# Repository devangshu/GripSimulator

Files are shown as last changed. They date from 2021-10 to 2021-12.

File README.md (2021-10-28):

# Grip Simulator

EE445L Final Project by Stefanie Thompson, Devangshu Goswami, Pulkit Mahajan, Anuv Gupta

## Notes

-   Password secret: `grip`
-   Serial format: `vpNum=vpValueNew\n` as `__=___...\n` ie. `03=245\n` or `12=1005\n`
    -   Two digits to represent the virtual pin number, then the full virtual pin integer value (any # of digits) followed by a newline character `\n`

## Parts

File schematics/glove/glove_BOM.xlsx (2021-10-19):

Part | Value | Device | Package | Description | POPULARITY | Column1
3.3V | TP_LOOP | TP_LOOP | TP_LOOP
5.0V | TP_LOOP | TP_LOOP | TP_LOOP
C1 | 4.7uf | CAPACITOR_POLARIZEDE5-6 | CAP200MILPOLARIZED | POLARIZED CAPACITOR, American symbol
C3 | 4.7uf | CAPACITOR_POLARIZEDE5-6 | CAP200MILPOLARIZED | POLARIZED CAPACITOR, American symbol
C5 | 4.7uf | CAPACITOR_POLARIZEDE5-6 | CAP200MILPOLARIZED | POLARIZED CAPACITOR, American symbol
C19 | 0.1uf | CAPACITOR050-024X044 | CAP200MIL | CAPACITOR, American symbol
GND | TP_LOOP | TP_LOOP | TP_LOOP
IC1 | LM2937 | LM2937 | TO220 | LM2937-2.5, LM2937-3.3 400mA and 500mA Voltage Regulators
JP1 |  | PINHD-1X2 | 1X02 | PIN HEADER
JP2 |  | PINHD-1X2 | 1X02 | PIN HEADER | 98
JP3 |  | PINHD-1X2 | 1X02 | PIN HEADER | 98
JP4 |  | PINHD-1X2 | 1X02 | PIN HEADER | 98
JP5 |  | PINHD-1X2 | 1X02 | PIN HEADER | 98
JP6 |  | PINHD-1X2 | 1X02 | PIN HEADER | 98
LED2 |  | LED3MM | LED3MM | Avago Technologies LED
R1 | 1K | RESISTOR0204/5 | RES200MIL | RESISTOR, American symbol
R3 | 10K | RESISTOR0204/7 | RES300MIL | RESISTOR, American symbol
U$1 | ESP_8266 | ESP_8266 | ESP8266
U$2 | TM4C_BP | TM4C_BP | TM4C_BOOSTER_PACK
U$5 | POWER_CONN | POWER_CONN | POWER_CONN
U$6 | SW_POWER_100MIL | SW_POWER_100MIL | SW_POWER

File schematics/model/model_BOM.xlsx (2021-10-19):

Column1 | Column2 | Column3 | Column4 | Column5 | Column6 | Column7
Part | Value | Device | Package | Description
3.3V | TP_LOOP | TP_LOOP | TP_LOOP
5.0V | TP_LOOP | TP_LOOP | TP_LOOP
C1 | 4.7uf | CAPACITOR_POLARIZEDE5-6 | CAP200MILPOLARIZED | POLARIZED CAPACITOR, American symbol
C3 | 4.7uf | CAPACITOR_POLARIZEDE5-6 | CAP200MILPOLARIZED | POLARIZED CAPACITOR, American symbol
C5 | 4.7uf | CAPACITOR_POLARIZEDE5-6 | CAP200MILPOLARIZED | POLARIZED CAPACITOR, American symbol
C19 | 0.1uf | CAPACITOR050-024X044 | CAP200MIL | CAPACITOR, American symbol
GND | TP_LOOP | TP_LOOP | TP_LOOP
IC1 | LM2937 | LM2937 | TO220 | LM2937-2.5, LM2937-3.3 400mA and 500mA Voltage Regulators
JP1 |  | PINHD-1X2 | 1X02 | PIN HEADER
JP2 |  | PINHD-1X3 | 1X03 | PIN HEADER
JP3 |  | PINHD-1X3 | 1X03 | PIN HEADER
JP4 |  | PINHD-1X3 | 1X03 | PIN HEADER
JP5 |  | PINHD-1X3 | 1X03 | PIN HEADER
JP6 |  | PINHD-1X3 | 1X03 | PIN HEADER
LED2 |  | LED3MM | LED3MM | Avago Technologies LED
R1 | 1K | RESISTOR0204/5 | RES200MIL | RESISTOR, American symbol
R3 | 10K | RESISTOR0204/7 | RES300MIL | RESISTOR, American symbol
U$1 | ESP_8266 | ESP_8266 | ESP8266
U$2 | TM4C_BP | TM4C_BP | TM4C_BOOSTER_PACK
U$5 | POWER_CONN | POWER_CONN | POWER_CONN
U$6 | SW_POWER_100MIL | SW_POWER_100MIL | SW_POWER

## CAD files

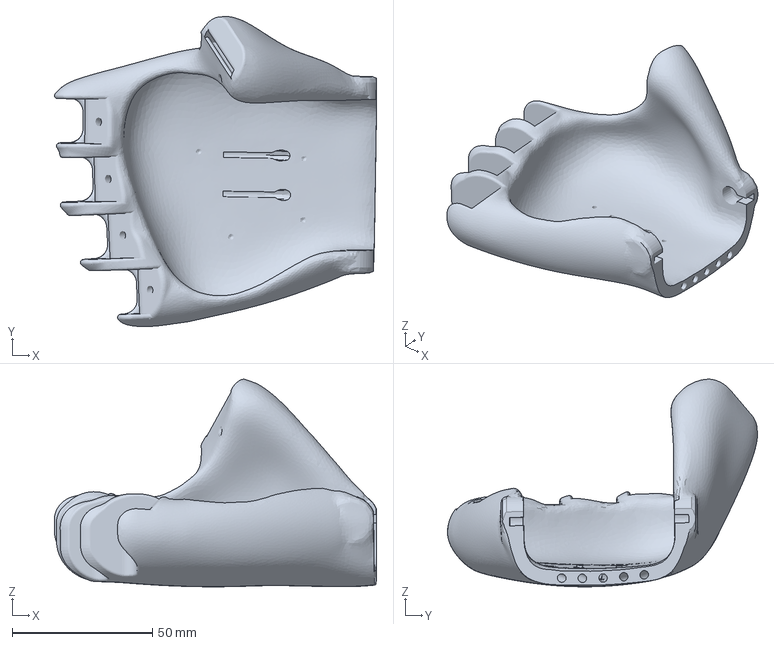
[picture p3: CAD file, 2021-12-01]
3d Models/RightHandPalmFullSizeBestQuality.3mf
115.0 x 110.7 x 74.1 mm

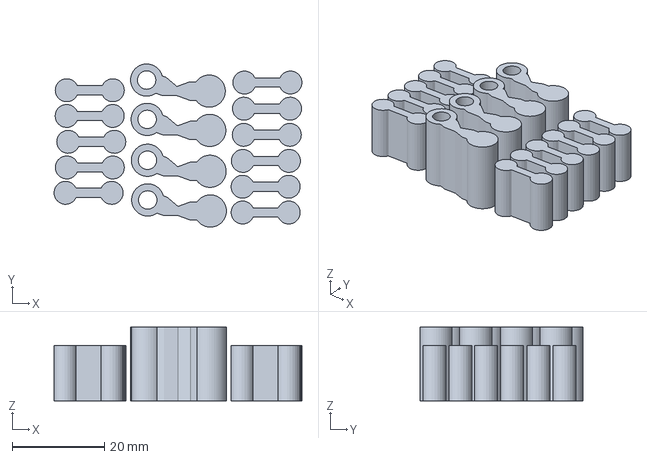
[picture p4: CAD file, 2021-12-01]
3d Models/FlexyPartProject.3mf
53.8 x 35.4 x 16.0 mm

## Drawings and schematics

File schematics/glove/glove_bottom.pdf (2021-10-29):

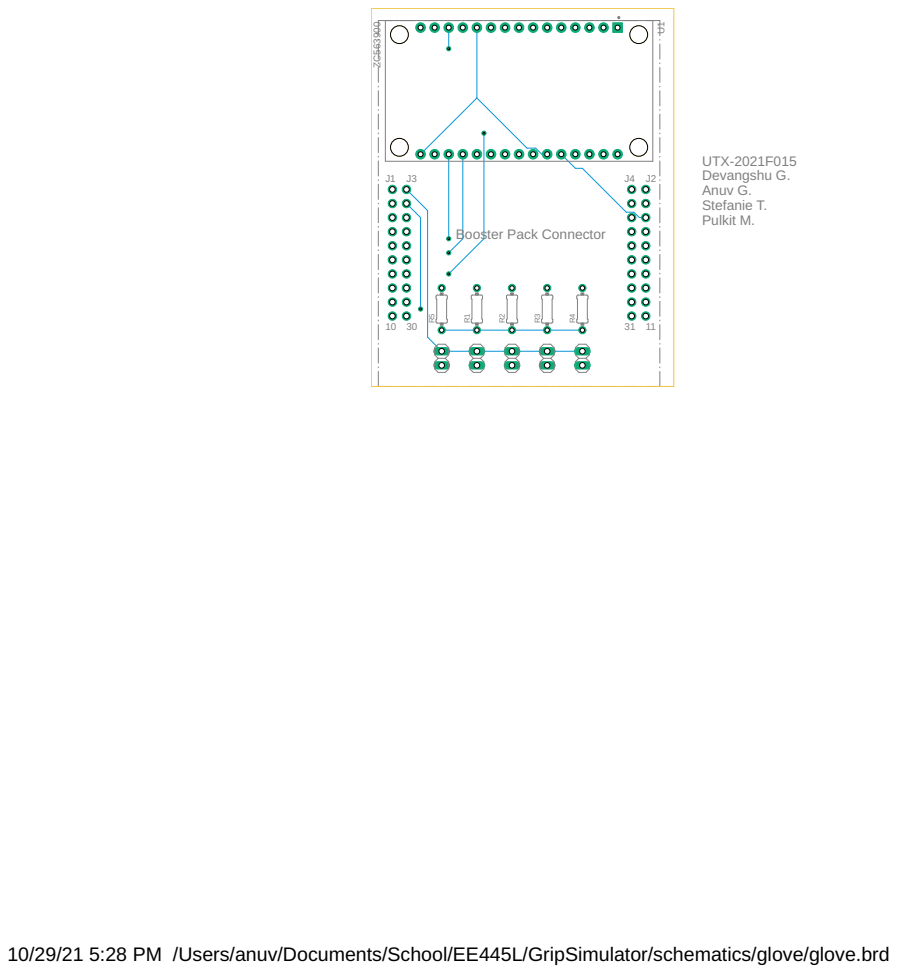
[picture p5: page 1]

Devangshu G. Anuv G. Stefanie T. Pulkit M.

10/29/21 5:28 PM /Users/anuv/Documents/School/EE445L/GripSimulator/schematics/glove/glove.brd

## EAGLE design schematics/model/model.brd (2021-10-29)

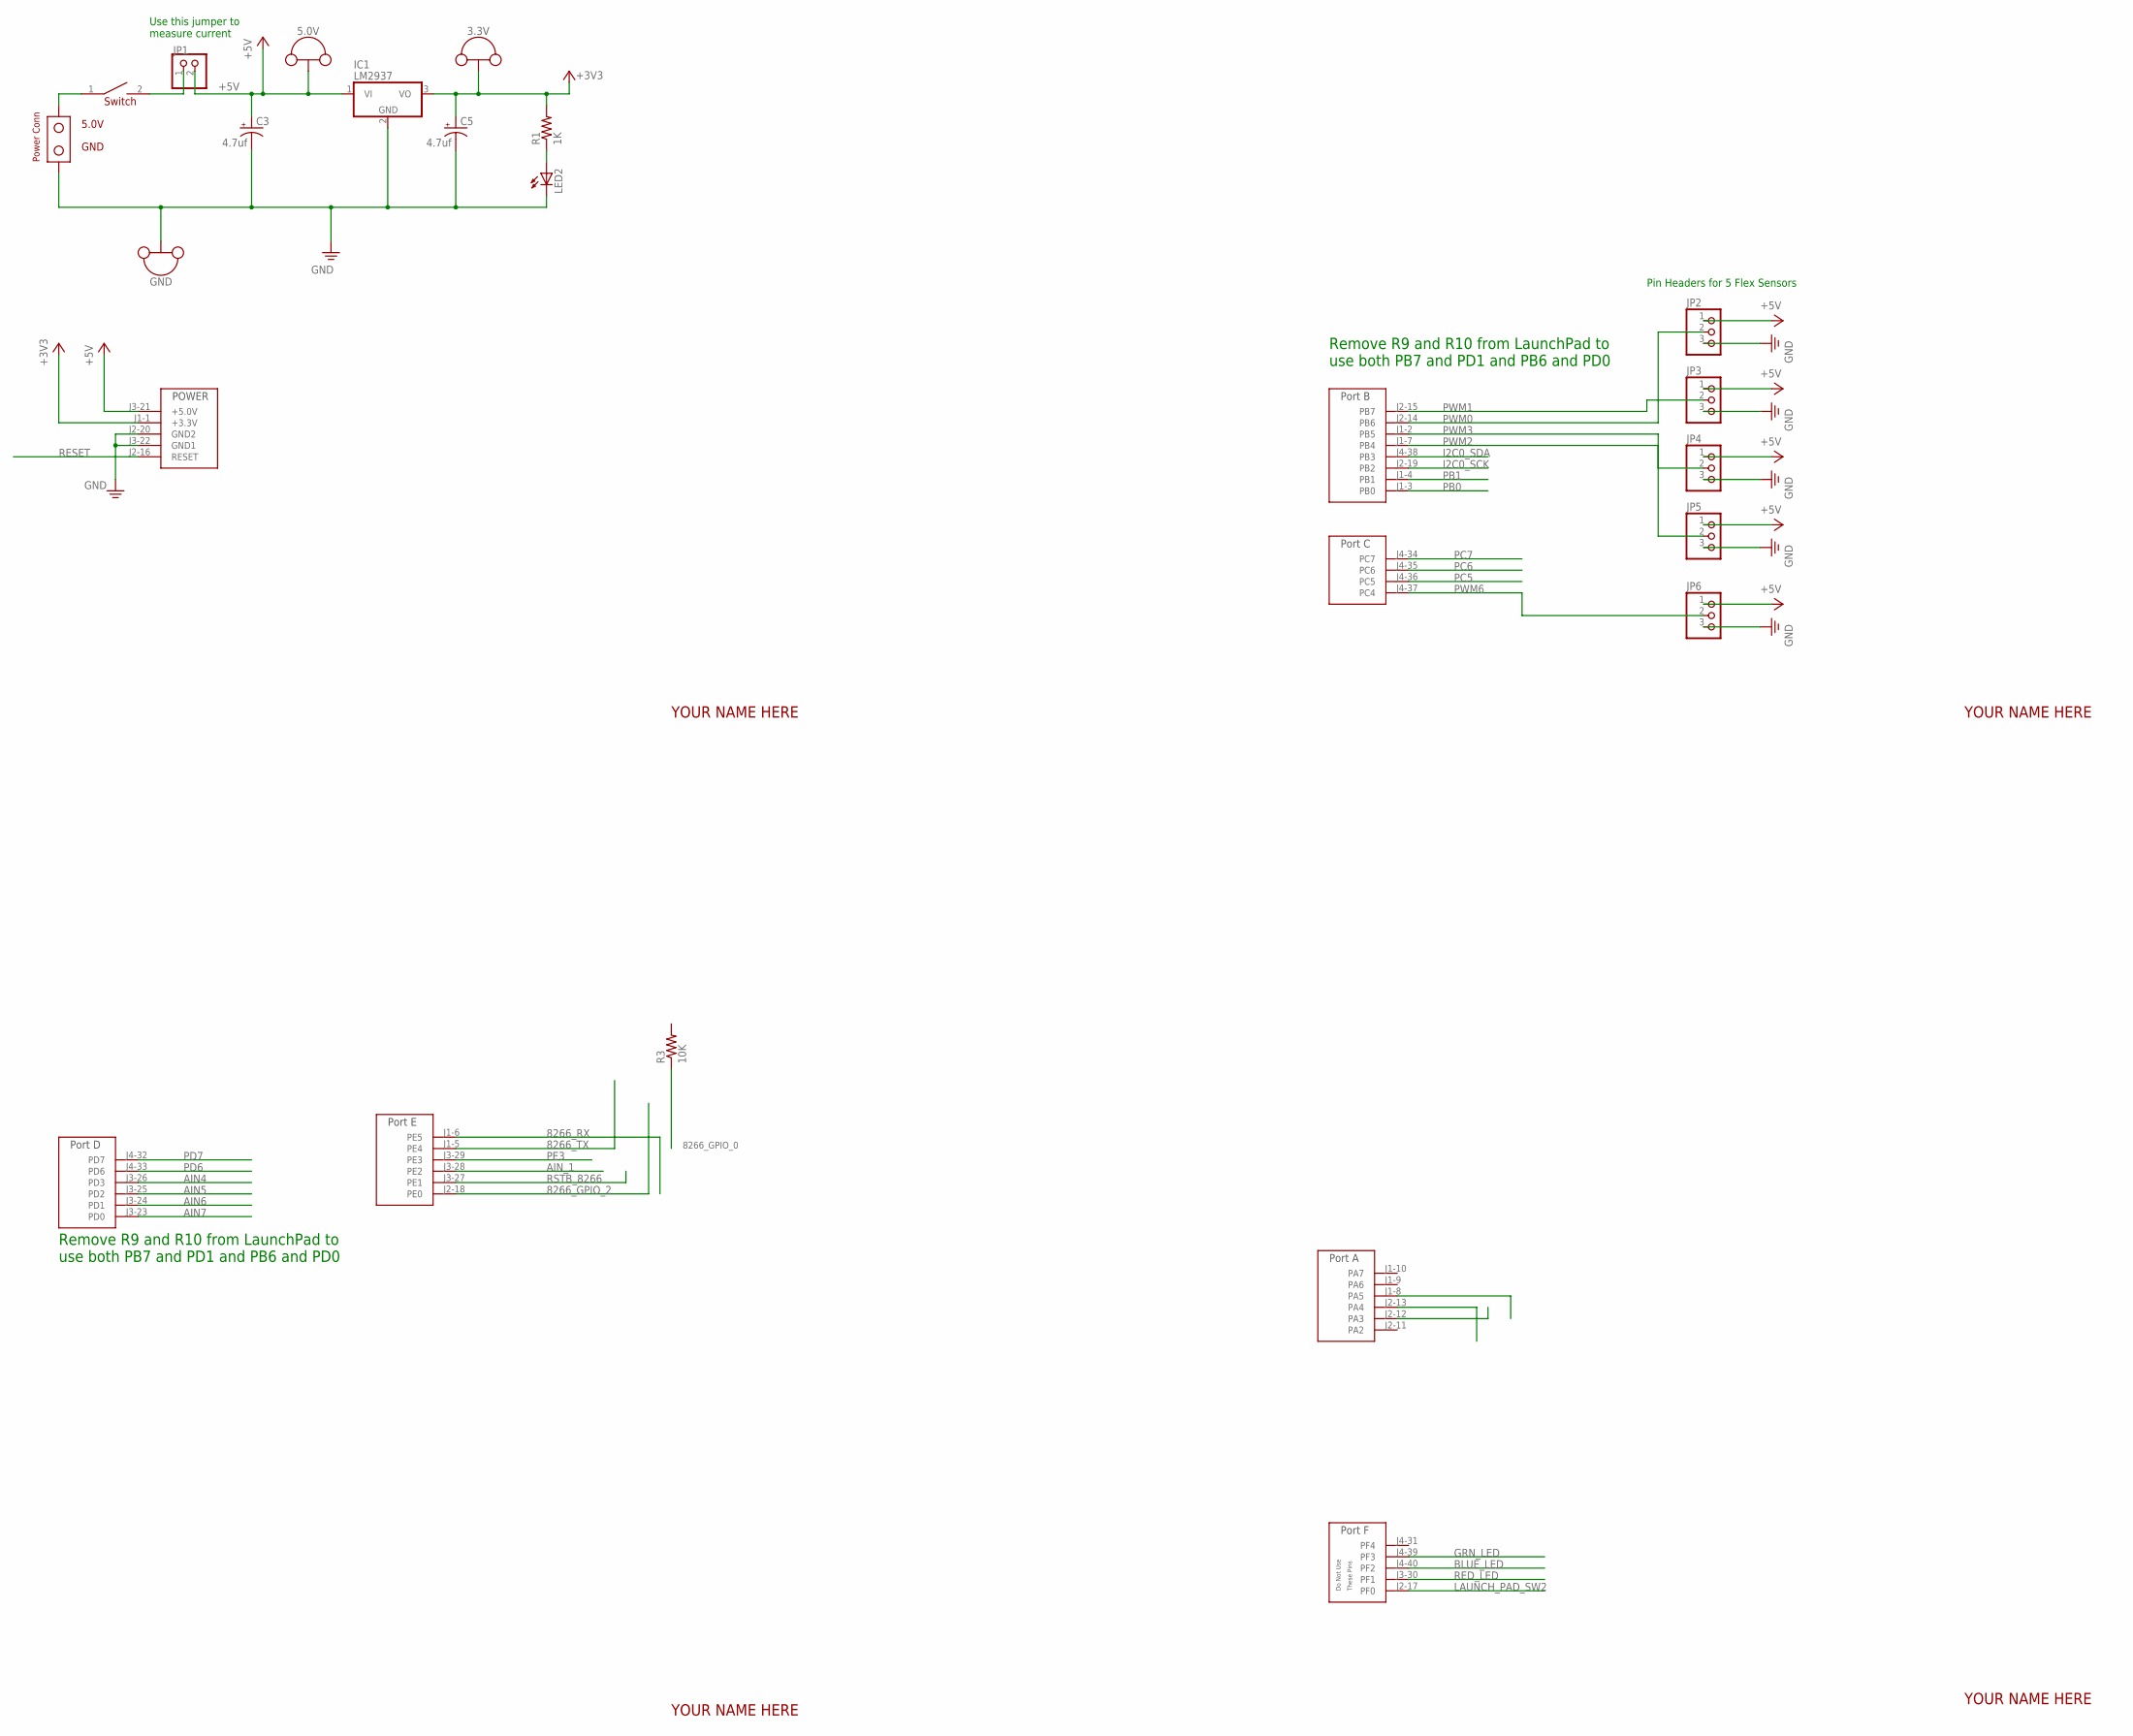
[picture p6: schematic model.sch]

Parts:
3.3V, 5.0V: TP_LOOP
C3, C5: 4.7uf; CAP200MILPOLARIZED
GND: TP_LOOP
IC1: LM2937; TO220
JP1: PINHD-1X2; 1X02
JP2, JP3, JP4, JP5, JP6: PINHD-1X3; 1X03
LED2: LED3MM
R1: 1K; RES200MIL
R3: 10K; RES300MIL
U$2: TM4C_BP; TM4C_BOOSTER_PACK
U$5: POWER_CONN
U$6: SW_POWER_100MIL; SW_POWER

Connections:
8266_GPIO_0: R3.1
8266_GPIO_2: U$2.J2-18 (PE0)
8266_RX: U$2.J1-6 (PE5)
8266_TX: U$2.J1-5 (PE4)
+3V3: 3.3V.P$1, 3.3V.P$2, C5.+, IC1.3 (VO), R1.2, U$2.J1-1 (+3.3V)
+5V: 5.0V.P$1, 5.0V.P$2, C3.+, IC1.1 (VI), JP1.2, JP2.1, JP3.1, JP4.1, JP5.1, JP6.1, U$2.J3-21 (+5.0V)
AIN4: U$2.J3-26 (PD3)
AIN5: U$2.J3-25 (PD2)
AIN6: U$2.J3-24 (PD1)
AIN7: U$2.J3-23 (PD0)
AIN_1: U$2.J3-28 (PE2)
BLUE_LED: U$2.J4-40 (PF2)
GND: C3.-, C5.-, GND.P$1, GND.P$2, IC1.2 (GND), JP2.3, JP3.3, JP4.3, JP5.3, JP6.3, LED2.K (C), U$2.J2-20 (GND2), U$2.J3-22 (GND1), U$5.GND
GRN_LED: U$2.J4-39 (PF3)
I2C0_SCK: U$2.J2-19 (PB2)
I2C0_SDA: U$2.J4-38 (PB3)
LAUNCH_PAD_SW2: U$2.J2-17 (PF0)
unnamed: JP1.1, U$6.2
unnamed: LED2.A, R1.1
unnamed: U$5.VDD, U$6.1
PB0: U$2.J1-3 (PB0)
PB1: U$2.J1-4 (PB1)
PC5: U$2.J4-36 (PC5)
PC6: U$2.J4-35 (PC6)
PC7: U$2.J4-34 (PC7)
PD6: U$2.J4-33 (PD6)
PD7: U$2.J4-32 (PD7)
PE3: U$2.J3-29 (PE3)
PWM0: JP2.2, U$2.J2-14 (PB6)
PWM1: JP3.2, U$2.J2-15 (PB7)
PWM2: JP4.2, U$2.J1-7 (PB4)
PWM3: JP5.2, U$2.J1-2 (PB5)
PWM6: JP6.2, U$2.J4-37 (PC4)
RED_LED: U$2.J3-30 (PF1)
RESET: U$2.J2-16 (RESET)
RSTB_8266: U$2.J3-27 (PE1)
ST7735_MISO: U$2.J2-13 (PA4)
ST7735_MOSI: U$2.J1-8 (PA5)
ST7735_TFT_CS: U$2.J2-12 (PA3)

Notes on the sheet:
Use this jumper to measure current
Remove R9 and R10 from LaunchPad to use both PB7 and PD1 and PB6 and PD0
YOUR NAME HERE
Pin Headers for 5 Flex Sensors

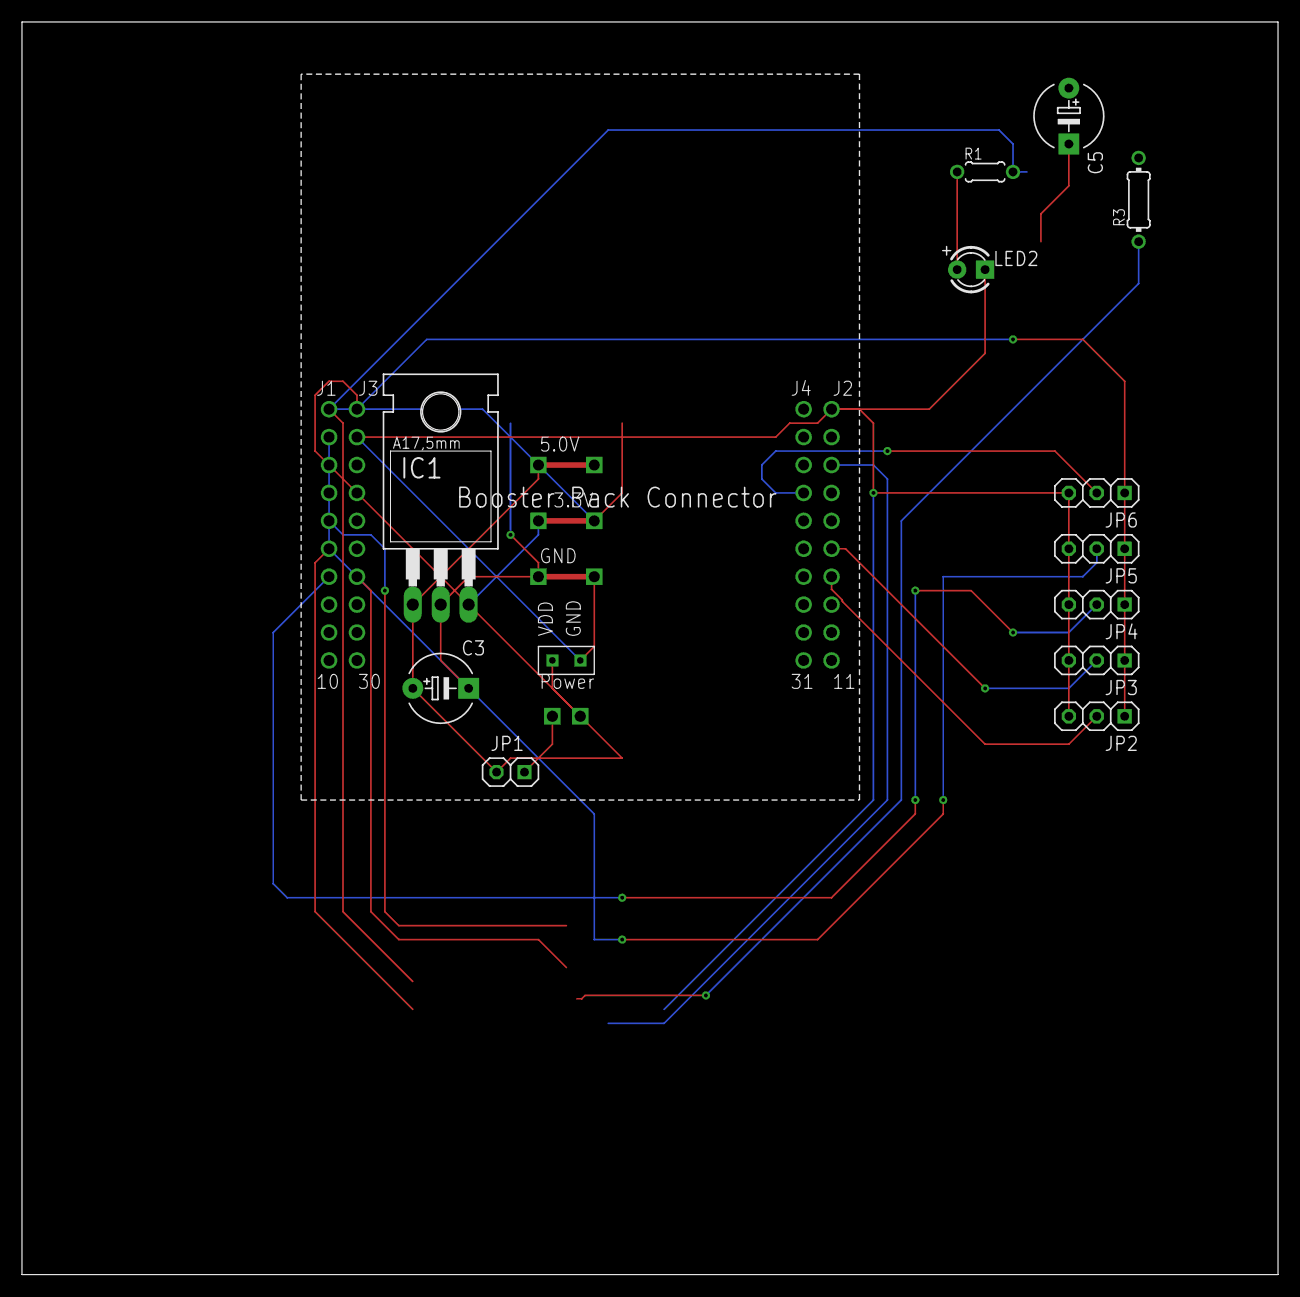
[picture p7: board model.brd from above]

Board: 2 copper layers, 114.3 x 114.0 mm, 18 parts (0 on the bottom side), 11 nets.

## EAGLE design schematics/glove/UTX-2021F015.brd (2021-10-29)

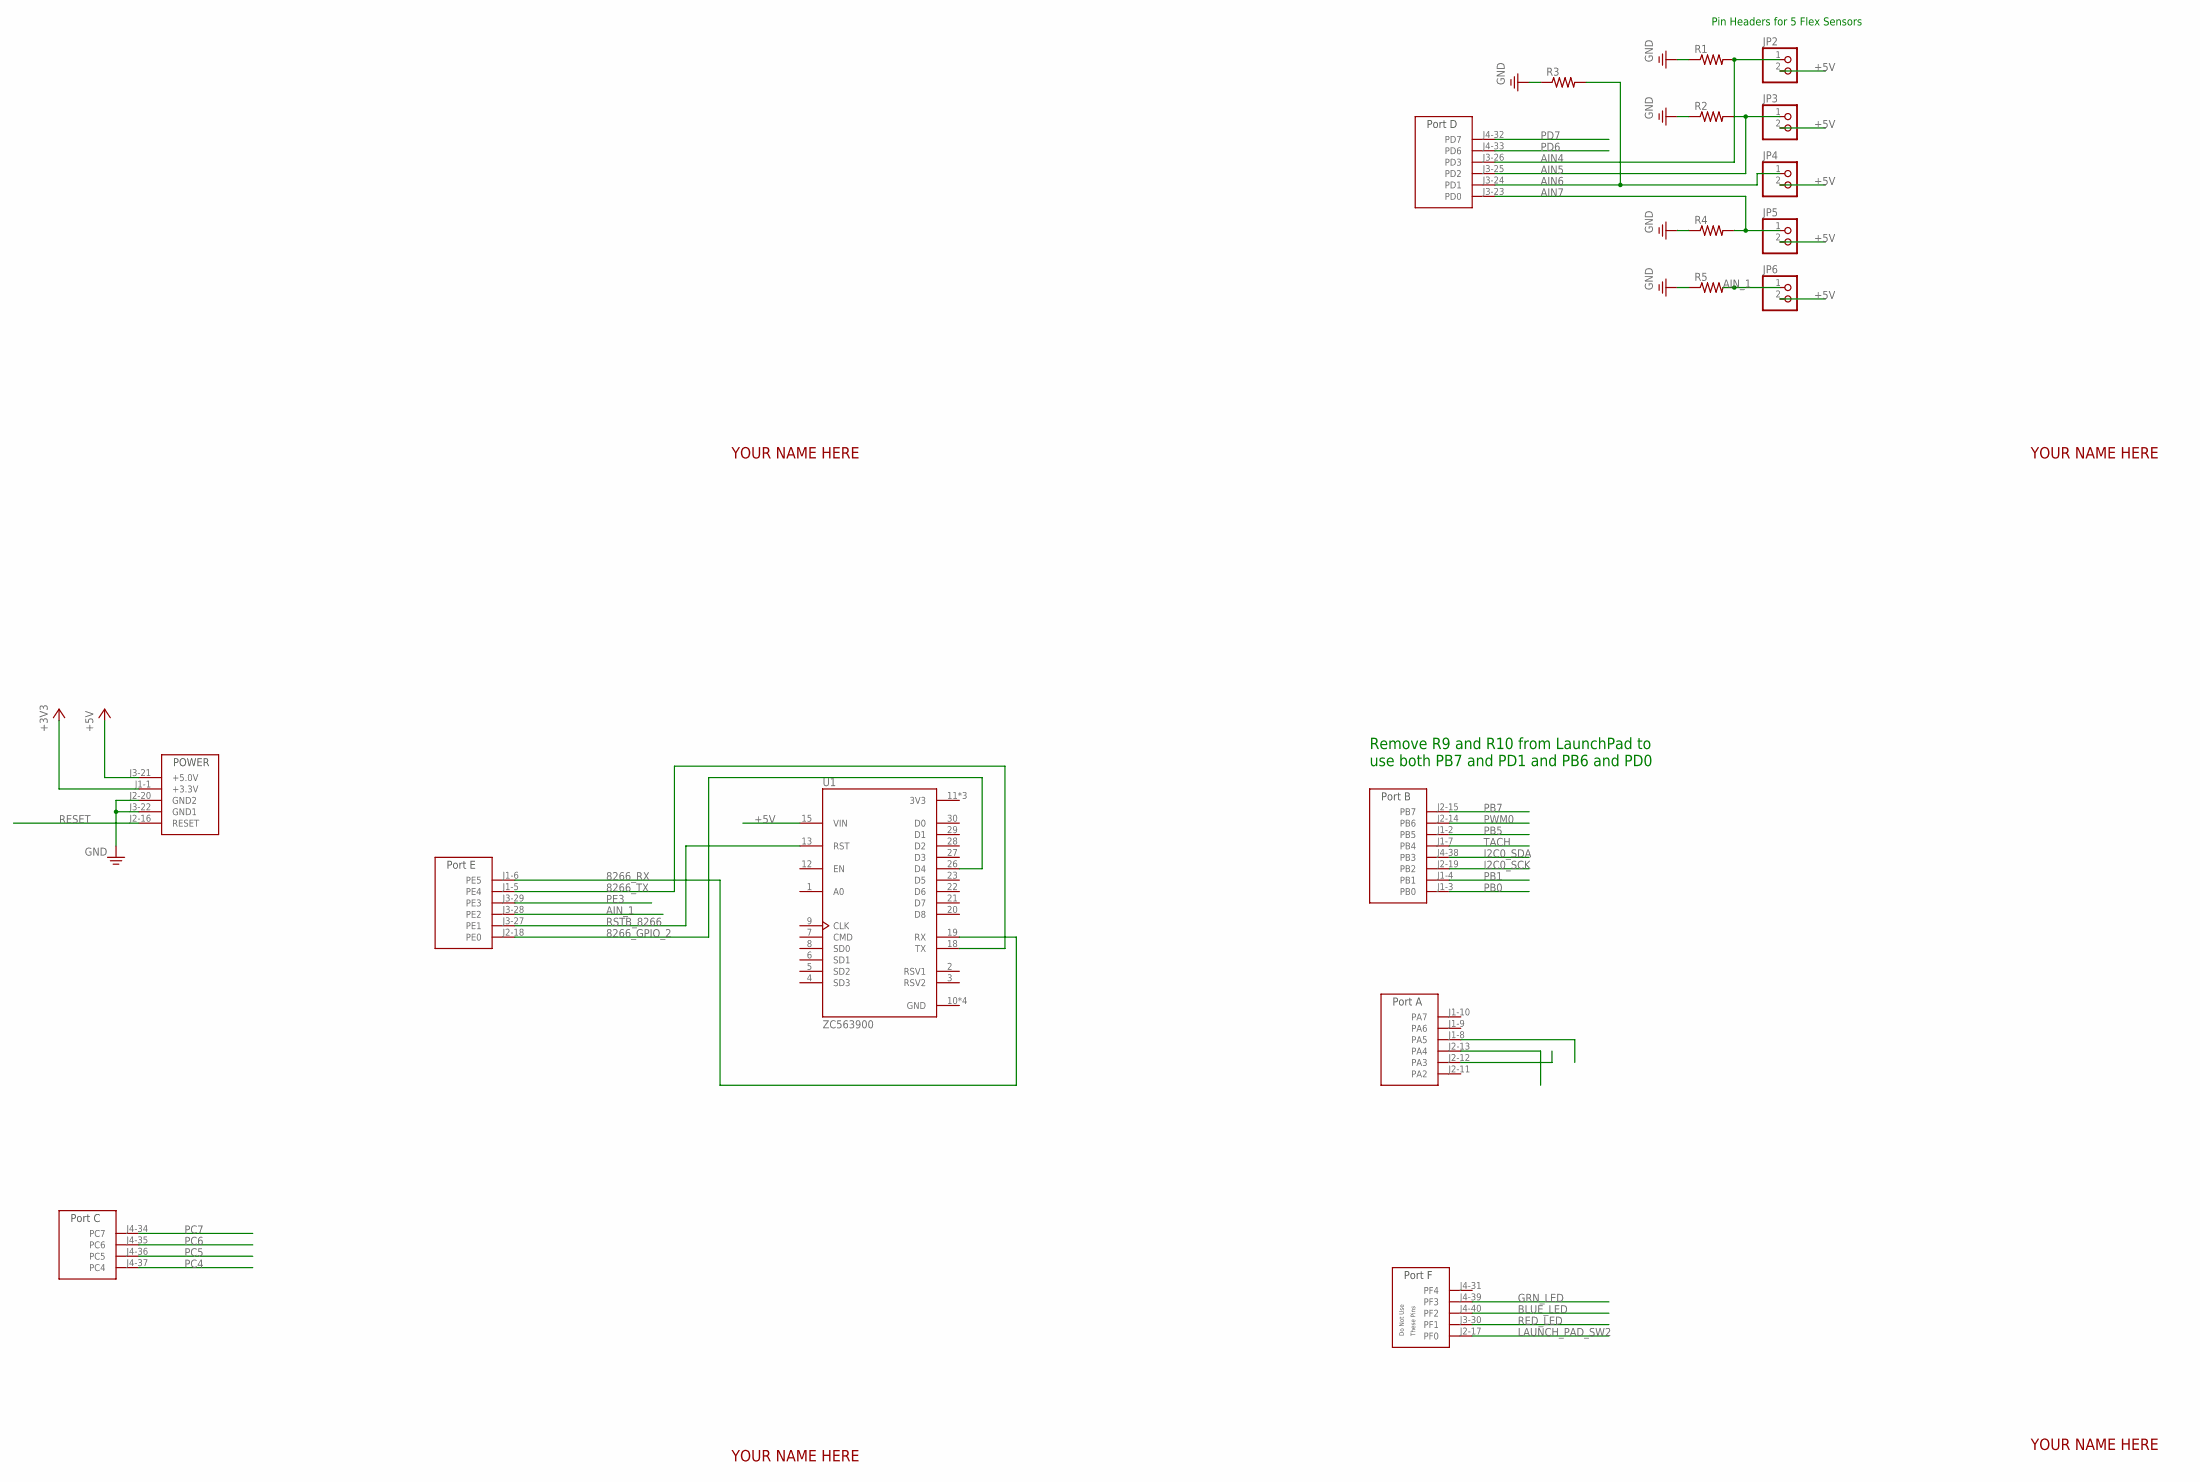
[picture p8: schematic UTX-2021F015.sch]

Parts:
JP2, JP3, JP4, JP5, JP6: PINHD-1X2; 1X02
R1, R2, R3, R4, R5: RESISTOR0204/7; RES300MIL
U1: ZC563900; MODULE_ZC563900
U$2: TM4C_BP; TM4C_BOOSTER_PACK

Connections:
3V3: U1.11 (3V3), U1.16 (3V3), U1.25 (3V3)
8266_GPIO_2: U1.26 (D4), U$2.J2-18 (PE0)
8266_RX: U1.19 (RX), U$2.J1-6 (PE5)
8266_TX: U1.18 (TX), U$2.J1-5 (PE4)
+3V3: U$2.J1-1 (+3.3V)
+5V: JP2.2, JP3.2, JP4.2, JP5.2, JP6.2, U1.15 (VIN), U$2.J3-21 (+5.0V)
AIN4: JP2.1, R1.2, U$2.J3-26 (PD3)
AIN5: JP3.1, R2.2, U$2.J3-25 (PD2)
AIN6: JP4.1, R3.2, U$2.J3-24 (PD1)
AIN7: JP5.1, R4.2, U$2.J3-23 (PD0)
AIN_1: JP6.1, R5.2, U$2.J3-28 (PE2)
BLUE_LED: U$2.J4-40 (PF2)
GND: R1.1, R2.1, R3.1, R4.1, R5.1, U1.10 (GND), U1.14 (GND), U1.17 (GND), U1.24 (GND), U$2.J2-20 (GND2), U$2.J3-22 (GND1)
GRN_LED: U$2.J4-39 (PF3)
I2C0_SCK: U$2.J2-19 (PB2)
I2C0_SDA: U$2.J4-38 (PB3)
LAUNCH_PAD_SW2: U$2.J2-17 (PF0)
PB0: U$2.J1-3 (PB0)
PB1: U$2.J1-4 (PB1)
PB5: U$2.J1-2 (PB5)
PB7: U$2.J2-15 (PB7)
PC4: U$2.J4-37 (PC4)
PC5: U$2.J4-36 (PC5)
PC6: U$2.J4-35 (PC6)
PC7: U$2.J4-34 (PC7)
PD6: U$2.J4-33 (PD6)
PD7: U$2.J4-32 (PD7)
PE3: U$2.J3-29 (PE3)
PWM0: U$2.J2-14 (PB6)
RED_LED: U$2.J3-30 (PF1)
RESET: U$2.J2-16 (RESET)
RSTB_8266: U1.13 (RST), U$2.J3-27 (PE1)
ST7735_MISO: U$2.J2-13 (PA4)
ST7735_MOSI: U$2.J1-8 (PA5)
ST7735_TFT_CS: U$2.J2-12 (PA3)
TACH: U$2.J1-7 (PB4)

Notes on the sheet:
Remove R9 and R10 from LaunchPad to use both PB7 and PD1 and PB6 and PD0
YOUR NAME HERE
Pin Headers for 5 Flex Sensors

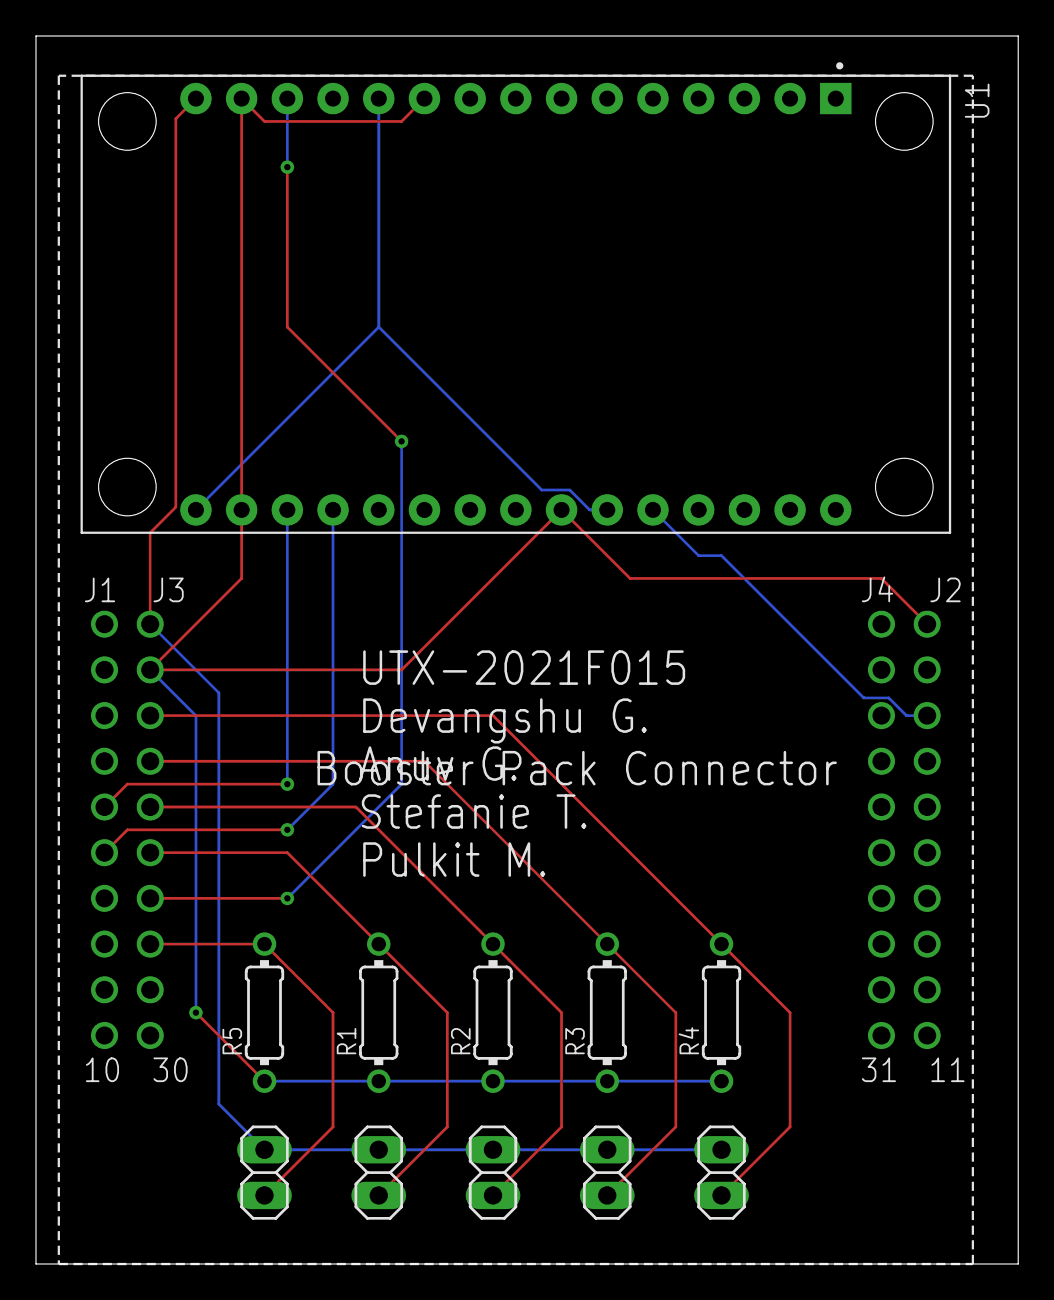
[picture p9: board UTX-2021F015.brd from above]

Board: 2 copper layers, 54.6 x 68.2 mm, 12 parts (0 on the bottom side), 12 nets.

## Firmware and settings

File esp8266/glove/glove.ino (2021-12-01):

/* GRIP SIMULATOR
 * glove device mqtt client driver
  */

#include "common.h"
#include "glove.h"

// variables
WiFiClient mqtt_wifi;
PubSubClient mqtt_client(mqtt_wifi);
boolean mqtt_client_online = false;
char wifi_ssid[50] = WIFI_SSID;
char mqtt_client_id[100] = MQTT_CLIENT_ID;
// leds
const int led_b_1 = LED_BUILTIN;
const int led_b_2 = 2;
// time
WiFiUDP ntpUDP;
NTPClient timeClient(ntpUDP, TIME_SERVER);
const long timeOffset = 60 * 60 * -6;  // GMT-6=60*60*-6
int resetOffset = 10;				   // in minutes
// parsing
int mb_i = 0;
char msgbuff[MSGBUFF_MAXLEN];

// init
void setup() {
	// serial
	if (DEBUG) {
		Serial.begin(9600);
		delay(5000);
	} else
		Serial.begin(9600);
	if (DEBUG) {
		Serial.printf("\r\n\r\n");
		Serial.printf("GRIP SIMULATOR\r\n");
		Serial.printf("GLOVE\r\n");
	}
	// boot
	Serial.printf("init\n");
	if (DEBUG) Serial.printf("\r\n");
	esp_boot_delay();
	// leds
	pinMode(led_b_1, OUTPUT);
	pinMode(led_b_2, OUTPUT);
	led_out_builtin(led_b_1, BRIGHTNESS_MIN);
	led_out_builtin(led_b_2, BRIGHTNESS_MIN);
	// wifi
	if (DEBUG) {
		Serial.print("[wifi] mac address: ");
		Serial.print(WiFi.macAddress().c_str());
		Serial.printf("\r\n");
		Serial.printf("[wifi] connecting to %s\r\n", &wifi_ssid);
	}
	WiFi.begin(WIFI_SSID, WIFI_PASS);
	while (WiFi.status() != WL_CONNECTED) delay(50);
	if (DEBUG) Serial.printf("[wifi] connected\r\n");
	IPAddress localIPAddress = WiFi.localIP();
	if (DEBUG) {
		Serial.printf("[wifi] ip address: ");
		Serial.print(localIPAddress);
		Serial.printf("\r\n");
	}
	// time
	if (DEBUG) Serial.printf("[time] connecting\r\n");
	timeClient.begin();
	timeClient.setTimeOffset(timeOffset);
	if (DEBUG) Serial.printf("[time] connected\r\n");
	// mqtt
	if (DEBUG) Serial.printf("[mqtt] connecting\r\n");
	sprintf(mqtt_client_id, "%s_device%d_%s", MQTT_CLIENT_ID, DEVICE_NUM, DEVICE_NAME);
	mqtt_client_online = true;
	mqtt_client.setServer(API_URL, API_PORT);
	mqtt_client.setCallback(mqtt_handler);
	// ready
	Serial.printf("ready\n");
	if (DEBUG) Serial.printf("\r\n");
}

// driver loop
void loop() {
	// onboard led output
	led_out_builtin(led_b_1, BRIGHTNESS_MAX);
	// monitor serial input
	serial_monitor();
	// reconnect/monitor mqtt client
	if (mqtt_client_online) {
		if (!mqtt_client.connected()) {
			mqtt_reconnect();
			led_out_builtin(led_b_2, BRIGHTNESS_MIN);
		} else {
			led_out_builtin(led_b_2, BRIGHTNESS_MAX);
		}
		mqtt_client.loop();
	}
	// check timer for reset
	reset_monitor();
}

// mqtt handlers
char mqtt_vpin_topic_buffer[15] = VIRTUALPIN_TOPIC;
char mqtt_vpin_value_buffer[15] = "";
void mqtt_reconnect() {
	while (!mqtt_client.connected()) {
		if (DEBUG) Serial.printf("[mqtt] attempting connection to %s:%d as \"%s\" \r\n", API_URL, API_PORT, mqtt_client_id);
		if (mqtt_client.connect(mqtt_client_id)) {
			if (DEBUG) Serial.printf("[mqtt] connected\r\n");
			// subscribe to necessary channels here
		} else {
			if (DEBUG) {
				Serial.print("[mqtt] failed, rc=");
				Serial.print(mqtt_client.state());
				Serial.printf(" retrying after 5 sec\r\n");
			}
			delay(5000);
		}
	}
}
void mqtt_handler(char* topic, byte* payload, unsigned int length) {
	if (DEBUG) {
		Serial.print(F("[mqtt] message received on topic "));
		Serial.print(topic);
		Serial.print(": \"");
		for (int i = 0; i < length; i++) {
			char rC = (char)payload[i];
			Serial.print(rC);
		}
		Serial.printf("\"\r\n");
	}
}
void mqtt_update(char* topic, char* message) {
	if (mqtt_client_online && mqtt_client.connected()) {
		mqtt_client.publish(topic, message);
	}
}
void mqtt_update_virtualpin(int vp_num, int vp_val) {
	sprintf(mqtt_vpin_topic_buffer, "%s_%d", VIRTUALPIN_TOPIC, vp_num);
	sprintf(mqtt_vpin_value_buffer, "%d", vp_val);
	mqtt_update(mqtt_vpin_topic_buffer, mqtt_vpin_value_buffer);
}

// serial monitor
void serial_monitor() {
	if (Serial.available()) {
		if (mb_i >= MSGBUFF_MAXLEN) {
			msgbuff[MSGBUFF_MAXLEN - 2] = '\n';
			msgbuff[MSGBUFF_MAXLEN - 1] = '\0';
			serial_monitor_input(msgbuff, mb_i);
			mb_i = 0;
		} else {
			char c = Serial.read();
			if (c != -1) {
				// Serial.print(c);
				if (c == '\n') {
					msgbuff[mb_i] = '\0';
					serial_monitor_input(msgbuff, mb_i);
					mb_i = 0;
				} else if (c != 0 && c > 32 && c < 126) {
					msgbuff[mb_i] = c;
					mb_i++;
				}
			}
		}
	}
}
void serial_monitor_input(char* msgbuff, int length) {
	if (DEBUG) Serial.println(msgbuff);
	if (memcmp(msgbuff + length - 5, "reset", 5) == 0) {
		esp_restart();
	} else if (msgbuff[2] == '=') {
		msgbuff[2] = '\0';
		int virtualpin_num = atoi(msgbuff);
		int virtualpin_val = atoi(msgbuff + 3);
//		if (DEBUG) Serial.printf("[serial] forwarding update VP%d: %d\r\n", virtualpin_num, virtualpin_val);
		mqtt_update_virtualpin(virtualpin_num, virtualpin_val);
	}
}

// esp control
boolean firstTimer = 1;
unsigned long epochTime = 0;
unsigned long nextEpochTime = 0;
void reset_monitor() {
	timeClient.update();
	nextEpochTime = timeClient.getEpochTime();
	if (nextEpochTime - epochTime > resetOffset * 60) {
		epochTime = nextEpochTime;
		if (DEBUG) {
			Serial.print(F("[time] epoch time: "));
			Serial.print(epochTime);
			Serial.printf("\r\n");
		}
		if (firstTimer == 1) {
			firstTimer = 0;
			delay(500);
		} else {
			esp_restart();
		}
	}
}
void esp_boot_delay() {
  for (uint8_t t = 2; t > 0; t--) {
    if (DEBUG) {
      Serial.printf("[boot] wait %d\r\n", t);
      Serial.flush();
    }
    delay(1000);
  }
}
void esp_restart() {
  if (DEBUG) {
    Serial.print(F("[boot] resetting..."));
    Serial.printf("\r\n");
  }
  ESP.restart();
}

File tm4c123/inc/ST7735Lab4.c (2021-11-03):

/***************************************************
  This is a library for the Adafruit 1.8" SPI display.
  This library works with the Adafruit 1.8" TFT Breakout w/SD card
  ----> http://www.adafruit.com/products/358
  as well as Adafruit raw 1.8" TFT display
  ----> http://www.adafruit.com/products/618

  Check out the links above for our tutorials and wiring diagrams
  These displays use SPI to communicate, 4 or 5 pins are required to
  interface (RST is optional)
  Adafruit invests time and resources providing this open source code,
  please support Adafruit and open-source hardware by purchasing
  products from Adafruit!

  Written by Limor Fried/Ladyada for Adafruit Industries.
  MIT license, all text above must be included in any redistribution
 ****************************************************/

// ST7735.c
// Runs on LM4F120/TM4C123
// Low level drivers for the ST7735 160x128 LCD based off of
// the file described above.
//    16-bit color, 128 wide by 160 high LCD
// Daniel Valvano
// January 15, 2020
// Augmented 7/17/2014 to have a simple graphics facility
// Tested with LaunchPadDLL.dll simulator 9/2/2014
// Modified for use of CS (simultaneous with other SPI slaves) 3/28/2016

/* This example accompanies the books
   "Embedded Systems: Introduction to ARM Cortex M Microcontrollers",
      ISBN: 978-1469998749, Jonathan Valvano, copyright (c) 2020
   "Embedded Systems: Real Time Interfacing to ARM Cortex M Microcontrollers",
      ISBN: 978-1463590154, Jonathan Valvano, copyright (c) 2020
   "Embedded Systems: Real-Time Operating Systems for ARM Cortex-M Microcontrollers",
      ISBN: 978-1466468863, Jonathan Valvano, copyright (c) 2020

 Copyright 2020 by Jonathan W. Valvano, valvano@mail.utexas.edu
    You may use, edit, run or distribute this file
    as long as the above copyright notice remains
 THIS SOFTWARE IS PROVIDED "AS IS".  NO WARRANTIES, WHETHER EXPRESS, IMPLIED
 OR STATUTORY, INCLUDING, BUT NOT LIMITED TO, IMPLIED WARRANTIES OF
 MERCHANTABILITY AND FITNESS FOR A PARTICULAR PURPOSE APPLY TO THIS SOFTWARE.
 VALVANO SHALL NOT, IN ANY CIRCUMSTANCES, BE LIABLE FOR SPECIAL, INCIDENTAL,
 OR CONSEQUENTIAL DAMAGES, FOR ANY REASON WHATSOEVER.
 For more information about my classes, my research, and my books, see
 http://users.ece.utexas.edu/~valvano/
 */

// hardware connections
// **********ST7735 TFT and SDC*******************
// ST7735
// Backlight (pin 10) connected to +3.3 V
// MISO (pin 9) unconnected
// SCK (pin 8) connected to PA2 (SSI0Clk)
// MOSI (pin 7) connected to PA5 (SSI0Tx)
// TFT_CS (pin 6) connected to PA3 (SSI0Fss)
// CARD_CS (pin 5) unconnected
// Data/Command (pin 4) connected to PA6 (GPIO), high for data, low for command
// RESET (pin 3) connected to PA7 (GPIO)
// VCC (pin 2) connected to +3.3 V
// Gnd (pin 1) connected to ground

// **********wide.hk ST7735R with ADXL345 accelerometer *******************
// Silkscreen Label (SDC side up; LCD side down) - Connection
// VCC  - +3.3 V
// GND  - Ground
// !SCL - PA2 Sclk SPI clock from microcontroller to TFT or SDC
// !SDA - PA5 MOSI SPI data from microcontroller to TFT or SDC
// DC   - PA6 TFT data/command
// RES  - PA7 TFT reset
// CS   - PA3 TFT_CS, active low to enable TFT
// *CS  - (NC) SDC_CS, active low to enable SDC
// MISO - (NC) MISO SPI data from SDC to microcontroller
// SDA  � (NC) I2C data for ADXL345 accelerometer
// SCL  � (NC) I2C clock for ADXL345 accelerometer
// SDO  � (NC) I2C alternate address for ADXL345 accelerometer
// Backlight + - Light, backlight connected to +3.3 V

// **********wide.hk ST7735R with ADXL335 accelerometer *******************
// Silkscreen Label (SDC side up; LCD side down) - Connection
// VCC  - +3.3 V
// GND  - Ground
// !SCL - PA2 Sclk SPI clock from microcontroller to TFT or SDC
// !SDA - PA5 MOSI SPI data from microcontroller to TFT or SDC
// DC   - PA6 TFT data/command
// RES  - PA7 TFT reset
// CS   - PA3 TFT_CS, active low to enable TFT
// *CS  - (NC) SDC_CS, active low to enable SDC
// MISO - (NC) MISO SPI data from SDC to microcontroller
// X� (NC) analog input X-axis from ADXL335 accelerometer
// Y� (NC) analog input Y-axis from ADXL335 accelerometer
// Z� (NC) analog input Z-axis from ADXL335 accelerometer
// Backlight + - Light, backlight connected to +3.3 V

// **********HiLetgo ST7735 TFT and SDC (SDC not tested)*******************
// ST7735
// LED-   (pin 16) TFT, connected to ground
// LED+   (pin 15) TFT, connected to +3.3 V
// SD_CS  (pin 14) SDC, chip select
// MOSI   (pin 13) SDC, MOSI
// MISO   (pin 12) SDC, MISO
// SCK    (pin 11) SDC, serial clock
// CS     (pin 10) TFT, PA3 (SSI0Fss)
// SCL    (pin 9)  TFT, SCK  PA2 (SSI0Clk)
// SDA    (pin 8)  TFT, MOSI PA5 (SSI0Tx)
// A0     (pin 7)  TFT, Data/Command PA6 (GPIO), high for data, low for command
// RESET  (pin 6)  TFT, to PA7 (GPIO)
// NC     (pins 3,4,5) not connected
// VCC    (pin 2)  connected to +3.3 V
// GND    (pin 1)  connected to ground

#include <stdio.h>
#include <stdint.h>
#include <stdlib.h>
#include "ST7735Lab4.h"
#include "tm4c123gh6pm.h"

// 16 rows (0 to 15) and 21 characters (0 to 20)
// Requires (11 + size*size*6*8) bytes of transmission for each character
uint32_t StX=0; // position along the horizonal axis 0 to 20
uint32_t StY=0; // position along the vertical axis 0 to 15
uint16_t StTextColor = ST7735_YELLOW;

#define ST7735_NOP     0x00
#define ST7735_SWRESET 0x01
#define ST7735_RDDID   0x04
#define ST7735_RDDST   0x09

#define ST7735_SLPIN   0x10
#define ST7735_SLPOUT  0x11
#define ST7735_PTLON   0x12
#define ST7735_NORON   0x13

#define ST7735_INVOFF  0x20
#define ST7735_INVON   0x21
#define ST7735_DISPOFF 0x28
#define ST7735_DISPON  0x29
#define ST7735_CASET   0x2A
#define ST7735_RASET   0x2B
#define ST7735_RAMWR   0x2C
#define ST7735_RAMRD   0x2E

#define ST7735_PTLAR   0x30
#define ST7735_COLMOD  0x3A
#define ST7735_MADCTL  0x36

#define ST7735_FRMCTR1 0xB1
#define ST7735_FRMCTR2 0xB2
#define ST7735_FRMCTR3 0xB3
#define ST7735_INVCTR  0xB4
#define ST7735_DISSET5 0xB6

#define ST7735_PWCTR1  0xC0
#define ST7735_PWCTR2  0xC1
#define ST7735_PWCTR3  0xC2
#define ST7735_PWCTR4  0xC3
#define ST7735_PWCTR5  0xC4
#define ST7735_VMCTR1  0xC5

#define ST7735_RDID1   0xDA
#define ST7735_RDID2   0xDB
#define ST7735_RDID3   0xDC
#define ST7735_RDID4   0xDD

#define ST7735_PWCTR6  0xFC

#define ST7735_GMCTRP1 0xE0
#define ST7735_GMCTRN1 0xE1

#define TFT_CS                  (*((volatile uint32_t *)0x40004020))
#define TFT_CS_LOW              0           // CS normally controlled by hardware
#define TFT_CS_HIGH             0x08
#define DC                      (*((volatile uint32_t *)0x40004100))
#define DC_COMMAND              0
#define DC_DATA                 0x40
#define RESET                   (*((volatile uint32_t *)0x40004200))
#define RESET_LOW               0
#define RESET_HIGH              0x80
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

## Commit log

2021-10-14 Final Project: Started Schematic for model hand
    [model.brd, model.sch]
2021-10-19 10-19 Prep: Updated Glove and Model schematics and BOMs
    [glove.brd, glove.csv, glove.sch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]
2021-10-25 add navbar & logout button to web client
2021-10-25 initial esp8266 glove and model drivers
2021-10-28 Added Valvanoware includes
    [OPT3101speedChoices.xlsx, SineTable.xlsx]
2021-10-28 ADC code and updated TM4C Includes
    [OPT3101speedChoices.xlsx, SineTable.xlsx, glove.csv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]
2021-10-29 Submitted PCB
    [UTX-2021F015.brd, UTX-2021F015.sch, model.brd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]
2021-10-29 add printouts for glove pcb
2021-11-02 Added basic servo drivers
2021-11-02 Modified Servo Test
2021-11-02 not working flex sensor code
    [ESPDriver.c, ST7735Lab4.c, UARTLab4.c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]
2021-11-03 test adc with flex sensor, fix ccs startup code, arrange modules
    [ADCDriver.c, ESPDriver.c]
2021-11-03 sync extraneous files
    [ADCSWTrigger.obj, CortexM.obj, LaunchPad.obj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]
2021-11-03 debug glove prototype & prepare code for model (tm4c+esp)
    [UARTLab4.obj, esp8266Lab4.obj]
2021-11-04 reformat, refactor, fix relative paths
    [ADCSWTrigger.obj, CortexM.obj, LaunchPad.obj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]
2021-11-29 So this should maybe plot our adc values in real time
2021-11-30 UNTESTED: Reading 5 adc channels
2021-11-30 Tested and working 5 channel ADC input
2021-12-01 fix esp8266 code for demo
    [common.h, glove.ino, model.ino]
2021-12-01 update adc driver for demo
2021-12-01 prevent spikes and sync with second laptop
    [ADCDriver.c, ESPDriver.c, PWMtest.c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]
2021-12-01 Changed PWM module, but 2 have same signal
2021-12-01 saving progress
    [FlexyPartProject.3mf, RightHandPalmFullSizeBestQuality.3mf]
2021-12-01 Integrating 5 channel ADC input
2021-12-01 Integrated model for 5 servos - UNTESTED
